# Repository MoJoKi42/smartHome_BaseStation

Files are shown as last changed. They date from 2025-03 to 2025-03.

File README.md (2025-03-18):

# smartHome_BaseStation

This Smart Home base station is built around an **ESP32** as the controller and uses an **RFM69HW** 433 MHz radio module for the wireless communication with sensors and actuators. For network communication with an MQTT server, a W5500 Ethernet PHY is used. Status information is displayed via status LEDs and an **I2C OLED display**. To improve the range of the radio system, I used an external dipol antenna. The PCB antenna works okay, but the range is not sufficient for the sensors outside my flat.

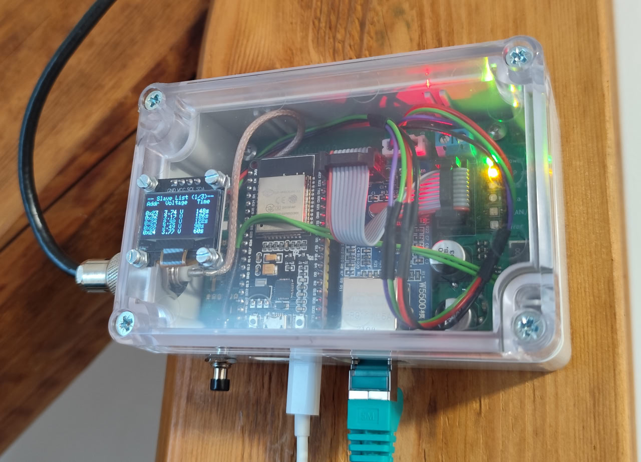
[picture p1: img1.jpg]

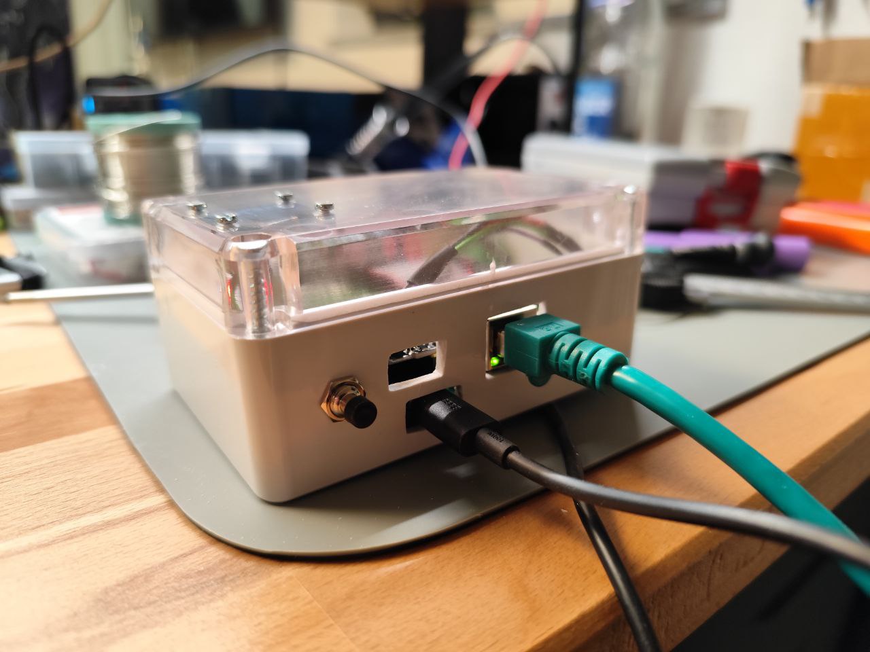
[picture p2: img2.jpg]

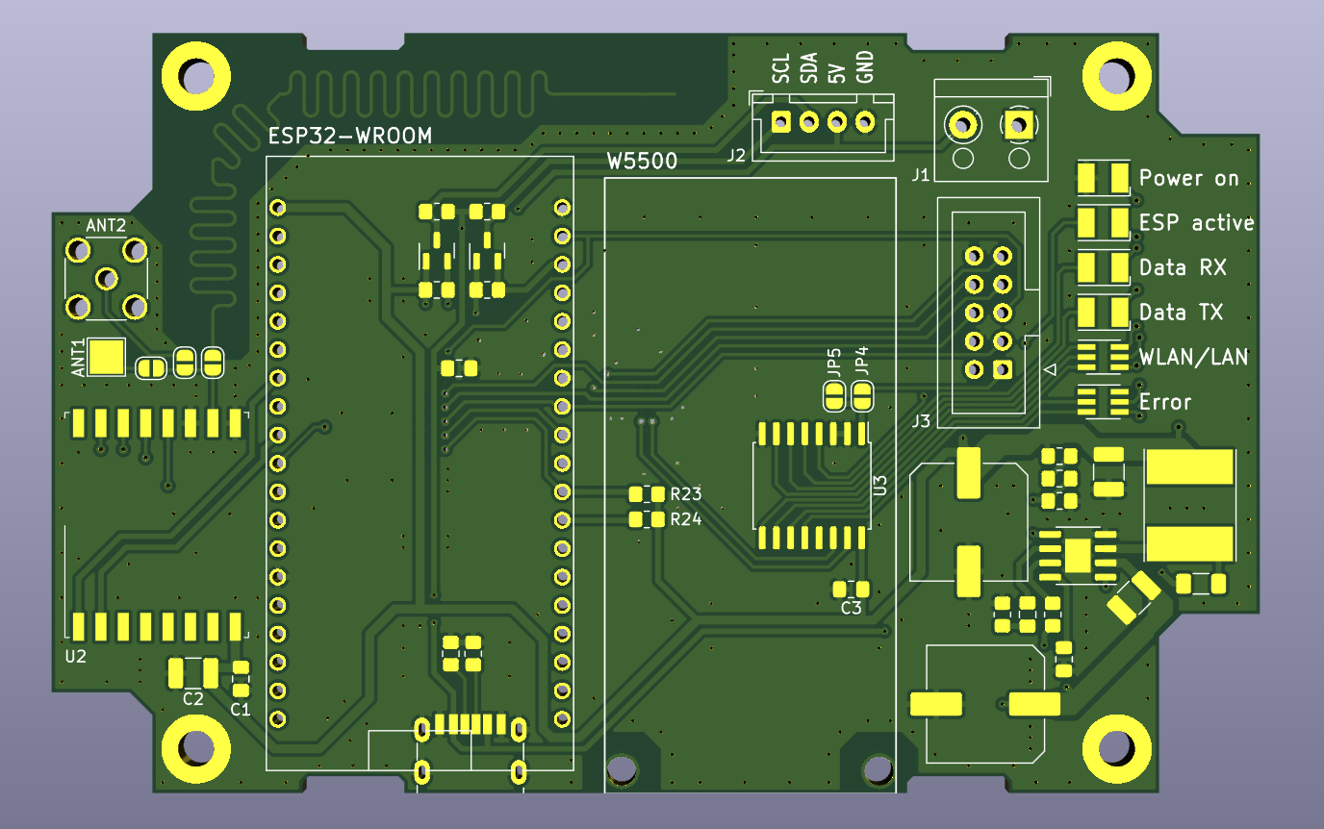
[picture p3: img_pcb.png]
img_pcb


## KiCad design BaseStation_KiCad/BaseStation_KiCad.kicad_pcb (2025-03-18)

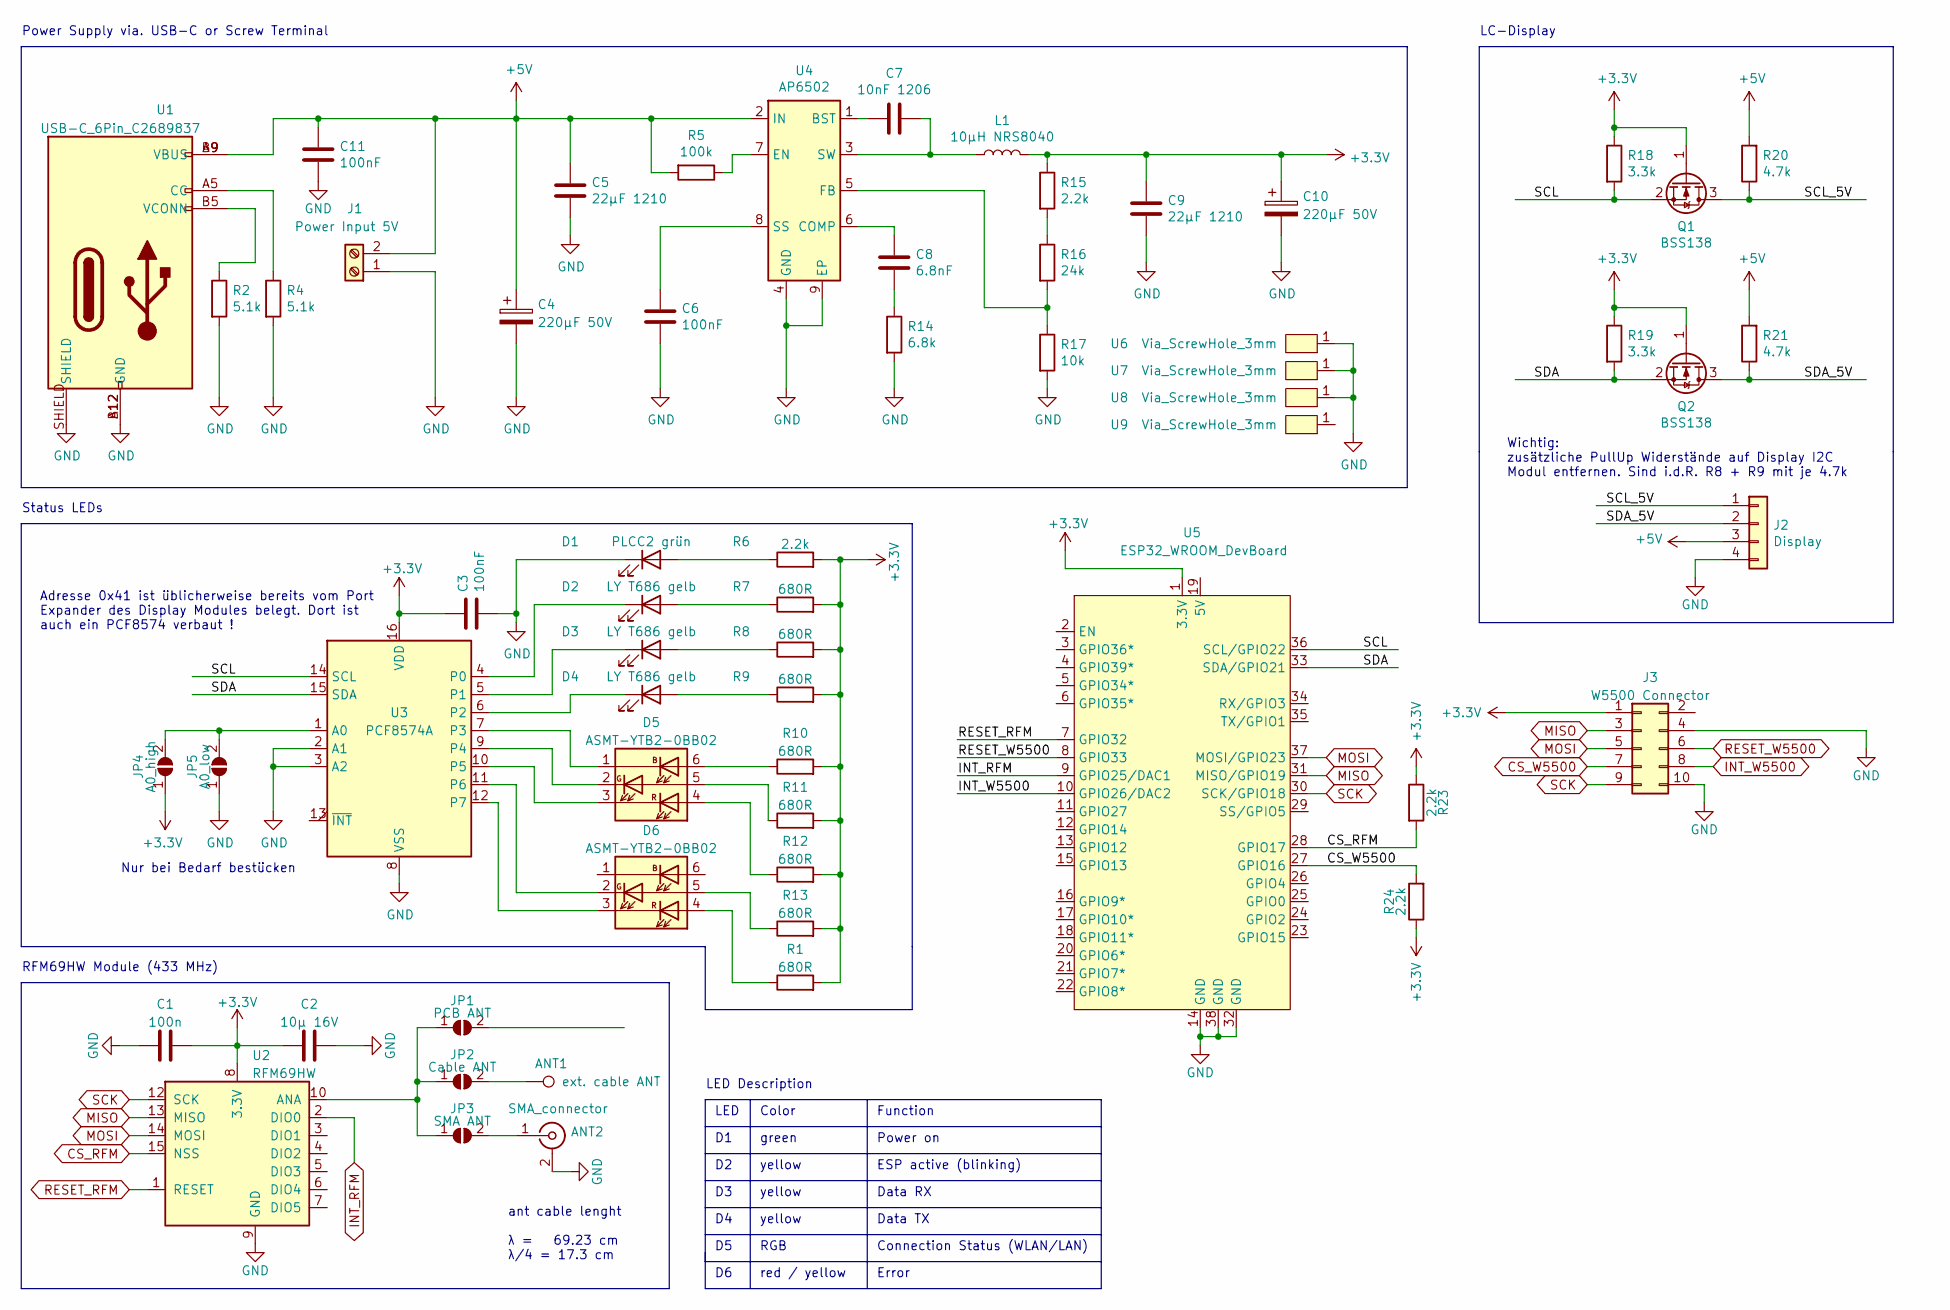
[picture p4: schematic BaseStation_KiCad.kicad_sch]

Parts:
ANT1: ext. cable ANT; TestPoint_Pad_3.0x3.0mm
ANT2: SMA_connector; SMA_Wurth_60312002114503_Vertical
C1: 100n; C_0805_2012Metric_Pad1.18x1.45mm_HandSolder
C2: 10µ 16V; C_1210_3225Metric_Pad1.33x2.70mm_HandSolder
C3, C6, C11: 100nF; C_0805_2012Metric_Pad1.18x1.45mm_HandSolder
C4, C10: 220µF 50V; C_Elec_10x10.2
C5, C9: 22µF 1210; C_1210_3225Metric_Pad1.33x2.70mm_HandSolder
C7: 10nF 1206; C_1206_3216Metric_Pad1.33x1.80mm_HandSolder
C8: 6.8nF; C_0805_2012Metric_Pad1.18x1.45mm_HandSolder
D1: PLCC2 grün; LED_PLCC-2_3.4x3.0mm_AK
D2, D3, D4: LY T686 gelb; LED_PLCC-2_3.4x3.0mm_AK
D5, D6: ASMT-YTB2-0BB02; LED_Avago_PLCC6_3x2.8mm
J1: Power Input 5V; TerminalBlock_RND_205-00001_1x02_P5.00mm_Horizontal
J2: Display; JST_XH_B4B-XH-A_1x04_P2.50mm_Vertical
J3: W5500 Connector; IDC-Header_2x05_P2.54mm_Vertical
JP1: PCB ANT; SolderJumper-2_P1.3mm_Open_RoundedPad1.0x1.5mm
JP2: Cable ANT; SolderJumper-2_P1.3mm_Open_RoundedPad1.0x1.5mm
JP3: SMA ANT; SolderJumper-2_P1.3mm_Open_RoundedPad1.0x1.5mm
JP4: A0_high; SolderJumper-2_P1.3mm_Open_RoundedPad1.0x1.5mm
JP5: A0_low; SolderJumper-2_P1.3mm_Open_RoundedPad1.0x1.5mm
L1: 10µH NRS8040; L_Taiyo-Yuden_NR-80xx_HandSoldering
Q1, Q2: BSS138; SOT-23
R1, R7, R8, R9, R10, R11, R12, R13: 680R; R_0805_2012Metric_Pad1.20x1.40mm_HandSolder
R2, R4: 5.1k; R_0805_2012Metric_Pad1.20x1.40mm_HandSolder
R5: 100k; R_0805_2012Metric_Pad1.20x1.40mm_HandSolder
R6, R15, R23, R24: 2.2k; R_0805_2012Metric_Pad1.20x1.40mm_HandSolder
R14: 6.8k; R_0805_2012Metric_Pad1.20x1.40mm_HandSolder
R16: 24k; R_0805_2012Metric_Pad1.20x1.40mm_HandSolder
R17: 10k; R_0805_2012Metric_Pad1.20x1.40mm_HandSolder
R18, R19: 3.3k; R_0805_2012Metric_Pad1.20x1.40mm_HandSolder
R20, R21: 4.7k; R_0805_2012Metric_Pad1.20x1.40mm_HandSolder
U1: USB-C_6Pin_C2689837
U2: RFM69HW; HOPERF_RFM69HW
U3: PCF8574A; SOIC-16W_7.5x10.3mm_P1.27mm
U4: AP6502; SOIC-8-1EP_3.9x4.9mm_P1.27mm_EP2.29x3mm
U5: ESP32_WROOM_DevBoard
U6, U7, U8, U9: Via_ScrewHole_3mm

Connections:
+3.3V: C1.2, C2.1, C3.1, C9.1, C10.1, J3.1, JP4.1 (A), L1.2, Q1.1 (G), Q2.1 (G), R1.2, R6.2, R7.2, R8.2, R9.2, R10.2, R11.2, R12.2, R13.2, R15.1, R18.1, R19.1, R23.1, R24.1, U2.8 (3.3V), U3.16 (VDD), U5.1 (3.3V)
+5V: C4.1, C5.1, C11.1, J1.2, J2.3, R5.2, R20.2, R21.2, U1.A9 (VBUS), U1.B9 (VBUS), U4.2 (IN)
/SCL: Q1.2 (S), R18.2, U3.14 (SCL), U5.36 (SCL/GPIO22)
/SCL_5V: J2.1, Q1.3 (D), R20.1
/SDA: Q2.2 (S), R19.2, U3.15 (SDA), U5.33 (SDA/GPIO21)
/SDA_5V: J2.2, Q2.3 (D), R21.1
CS_RFM: R23.2, U2.15 (NSS), U5.28 (GPIO17)
CS_W5500: J3.7, R24.2, U5.27 (GPIO16)
GND: ANT2.2 (Ext), C1.1, C2.2, C3.2, C4.2, C5.2, C6.2, C9.2, C10.2, C11.2, D1.1 (K), J1.1, J2.4, J3.4, J3.10, JP5.1 (A), R2.2, R4.2, R14.2, R17.2, U1.A12 (GND), U1.B12 (GND), U1.SHIELD, U2.9 (GND), U2.11 (GND), U3.2 (A1), U3.3 (A2), U3.8 (VSS), U4.4 (GND), U4.9 (EP), U5.14 (GND), U5.32 (GND), U5.38 (GND), U6.1, U7.1, U8.1
INT_RFM: U2.2 (DIO0), U5.9 (GPIO25/DAC1)
INT_W5500: J3.8, U5.10 (GPIO26/DAC2)
MISO: J3.3, U2.13 (MISO), U5.31 (MISO/GPIO19)
MOSI: J3.5, U2.14 (MOSI), U5.37 (MOSI/GPIO23)
unnamed: ANT1.1, JP2.2 (B)
unnamed: ANT2.1 (In), JP3.2 (B)
unnamed: C6.1, U4.8 (SS)
unnamed: C7.1, L1.1, U4.3 (SW)
unnamed: C7.2, U4.1 (BST)
unnamed: C8.1, U4.6 (COMP)
unnamed: C8.2, R14.1
unnamed: D1.2 (A), R6.1
unnamed: D2.1 (K), U3.4 (P0)
unnamed: D2.2 (A), R7.1
unnamed: D3.1 (K), U3.5 (P1)
unnamed: D3.2 (A), R8.1
unnamed: D4.1 (K), U3.6 (P2)
unnamed: D4.2 (A), R9.1
unnamed: D5.1 (KB), U3.7 (P3)
unnamed: D5.2 (KG), U3.9 (P4)
unnamed: D5.3 (KR), U3.10 (P5)
unnamed: D5.4 (AR), R12.1
unnamed: D5.5 (AG), R11.1
unnamed: D5.6 (AB), R10.1
unnamed: D6.2 (KG), U3.11 (P6)
unnamed: D6.3 (KR), U3.12 (P7)
unnamed: D6.4 (AR), R1.1
unnamed: D6.5 (AG), R13.1
unnamed: JP1.1 (A), JP2.1 (A), JP3.1 (A), U2.10 (ANA)
unnamed: R2.1, U1.B5 (VCONN)
unnamed: R4.1, U1.A5 (CC)
unnamed: R5.1, U4.7 (EN)
unnamed: R15.2, R16.1
unnamed: R16.2, R17.1, U4.5 (FB)
unnamed: JP4.2 (B), JP5.2 (B), U3.1 (A0)
RESET_RFM: U2.1 (RESET), U5.7 (GPIO32)
RESET_W5500: J3.6, U5.8 (GPIO33)
SCK: J3.9, U2.12 (SCK), U5.30 (SCK/GPIO18)

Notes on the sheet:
RFM69HW Module (433 MHz)
Connection Status (WLAN/LAN)
Wichtig: zusätzliche PullUp Widerstände auf Display I2C Modul entfernen. Sind i.d.R. R8 + R9 mit je 4.7k
Function
LED
ESP active (blinking)
RGB
LC-Display
green
ant cable lenght λ = 69.23 cm λ/4 = 17.3 cm
Power Supply via. USB-C or Screw Terminal
yellow
LED Description
Data RX
red / yellow
Error
Adresse 0x41 ist üblicherweise bereits vom Port Expander des Display Modules belegt. Dort ist auch ein PCF8574 verbaut !
Status LEDs
Color
Nur bei Bedarf bestücken
Data TX
Power on

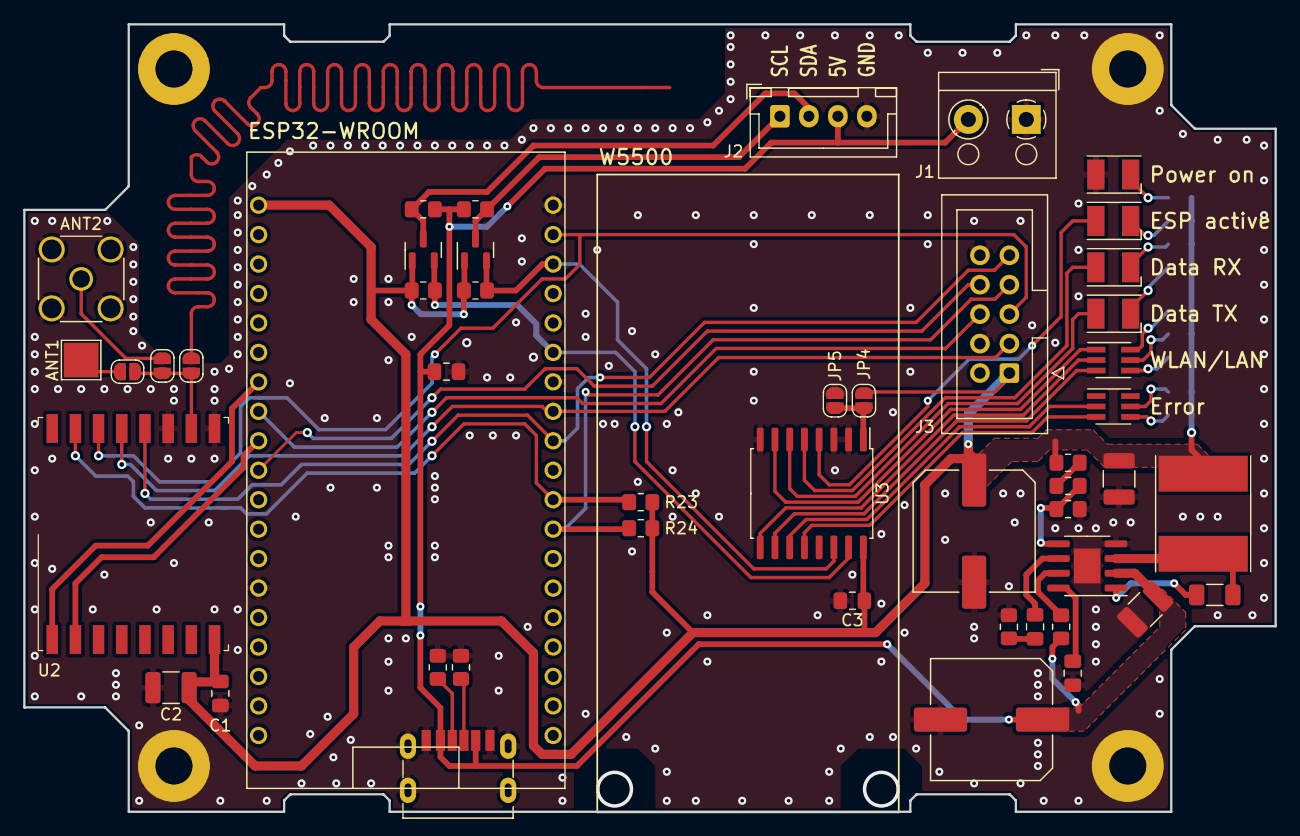
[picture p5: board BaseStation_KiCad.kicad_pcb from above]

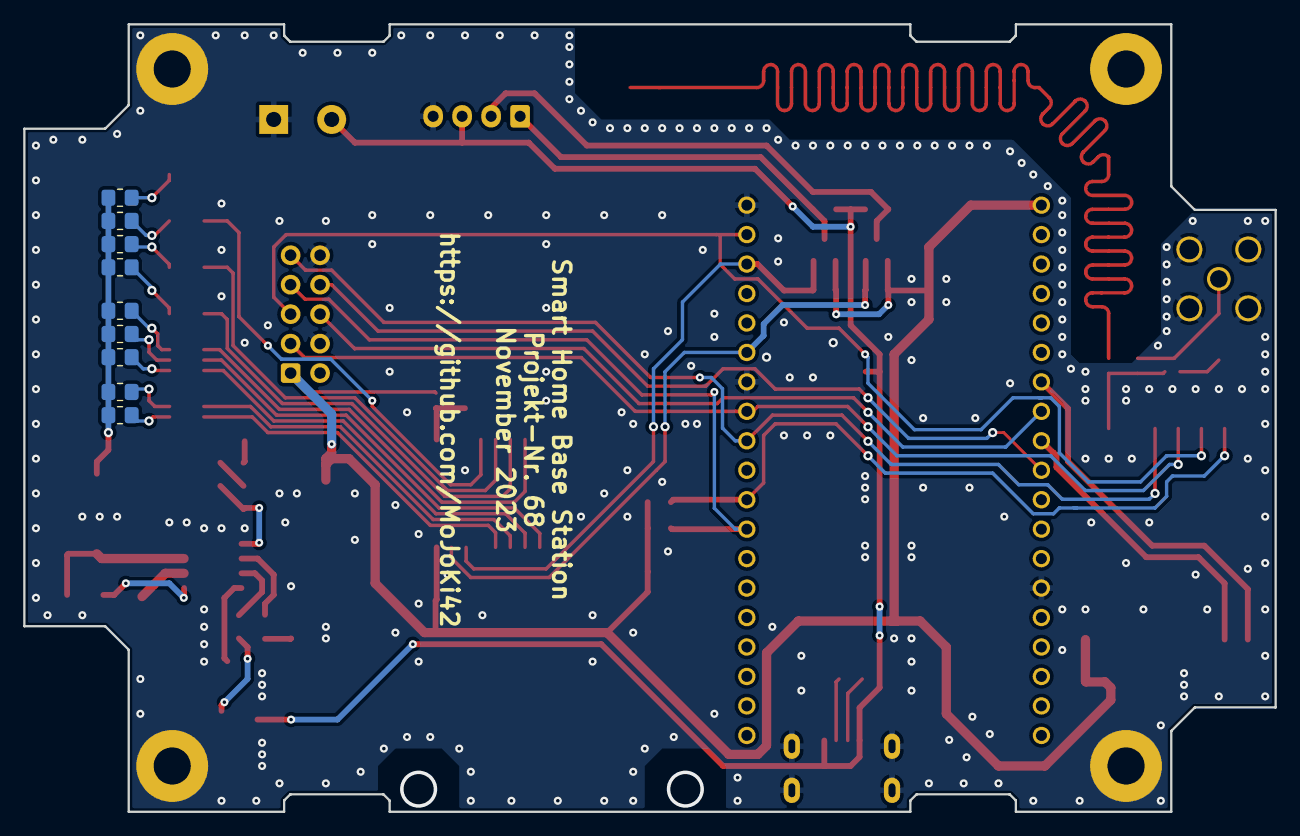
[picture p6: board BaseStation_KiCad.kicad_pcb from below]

Board: 2 copper layers, 107.9 x 67.9 mm, 61 parts (9 on the bottom side), 47 nets.

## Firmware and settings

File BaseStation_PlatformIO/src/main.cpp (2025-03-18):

#include <Arduino.h>
#include <PCF8574.h>
#include <Ethernet.h>
#include <Wire.h>
#include <SPI.h>
#include <RFM69.h>
#include <Adafruit_GFX.h>
#include <Adafruit_SSD1306.h>
#include <PubSubClient.h>
#include "disp.h"
#include "main.h"
#include "radio.h"

// Debug Konsole:
// sudo minicom -D /dev/ttyUSB0 -b 115200
// (to exit: Strg+A -> Q -> Enter)


radio_t radio_drv;
IPAddress ipAddress;
PubSubClient mqttClient;
EthernetClient ethClient;
uint32_t lastMqttPublishTime = 0;


// PCF8574 (for LEDs)
PCF8574 LEDs_PCF8574(0x39);

// OLED
#define OLED_WIDTH  128
#define OLED_HEIGHT 64
Adafruit_SSD1306 display(OLED_WIDTH, OLED_HEIGHT);
disp_t disp;

// RFM69
SPIClass * vspi = NULL;
RFM69 radio(PIN_CS_RFM, PIN_INT_RFM, true, vspi);

// prototypes
void macCharArrayToBytes(const char* str, byte* bytes);
void ethernetWizReset(const uint8_t resetPin);
void connectEthernet();
void mqttCallback(char* topic, byte* payload, unsigned int length);
void mqttReconnect();
void publish_mqtt(uint8_t nodeID, char* payload, uint8_t payload_lenght);
uint32_t time_func(uint32_t time_diff);

// prototypes rfm + receive function
uint8_t rfm_transmit(uint8_t dest, uint8_t* data, uint8_t len);
uint8_t rfm_receive(uint8_t* src, uint8_t* data, uint8_t* len);
uint8_t rfm_sendACK(uint8_t dest);
uint8_t rfm_ACKReceived(uint8_t dest);
uint8_t rfm_ACKRequested(uint8_t src);
uint8_t rfm_receiveDone(void);
void receive(uint8_t source, uint8_t* data, uint16_t len);

// variables
static uint32_t time_rxLED = time_func(0);

void setup() {
  Serial.begin(115200);   // init UART
  LEDs_PCF8574.begin();   // init PCF8574
  LEDs_PCF8574.write(LED_status_LAN_red,   0);
  LEDs_PCF8574.write(LED_status_error_red, 0);

  // Outputs
  pinMode(PIN_BUTTON, INPUT_PULLUP);

  // OLED
  display.begin(SSD1306_SWITCHCAPVCC, 0x3C);
  display.clearDisplay();
  display.display();
  display.setTextSize(1);
  display.setTextColor(SSD1306_WHITE);

  // Display Lib init
  disp_init(&disp, &display, ETHERNET_IP, MQTT_HOSTNAME);

  // MQTT / Ethernet
  connectEthernet();
  ethClient.setConnectionTimeout(1000);
  mqttClient.setClient(ethClient);
  mqttClient.setServer(MQTT_HOSTNAME, MQTT_PORT);
  mqttReconnect();

  // RFM69 init
  vspi = new SPIClass(VSPI);
  radio.initialize(FREQUENCY,NODEID,NETWORKID);
  radio.setHighPower();
  radio.encrypt(ENCRYPTKEY);

  // radio lib init
  radio_init(&radio_drv, NODEID);
  radio_set_cb_rfm (&radio_drv, (void*)rfm_transmit, (void*)rfm_receive, (void*)rfm_sendACK, (void*)rfm_ACKReceived, (void*)rfm_ACKRequested, (void*)rfm_receiveDone);
  radio_set_cb_func(&radio_drv, (void*)receive, (void*)delay, (void*)NULL);
}

void loop() {

  // MQTT / Ethernet connecting functions
  if (!ethClient.connected()) {
    LEDs_PCF8574.write(LED_status_LAN_red, 0);
  } else {
    LEDs_PCF8574.write(LED_status_LAN_red, 1);
  }
  if (!mqttClient.connected()) {
    LEDs_PCF8574.write(LED_status_error_red, 0);
    mqttReconnect();
  } else {
    LEDs_PCF8574.write(LED_status_error_red, 1);
  }
  mqttClient.loop();

  // LED status
  static uint32_t time_StatusLED = time_func(0);
  if (time_func(time_StatusLED) > 800) {
    LEDs_PCF8574.toggle(LED_status_ESP_active);
    time_StatusLED = time_func(0);
  }

  // LEDs tx + rx
  static uint32_t time_txLED = time_func(0);
  if (!radio_buffer_empty_tx(&radio_drv)) {
    LEDs_PCF8574.write(LED_status_data_TX, 0);
    time_txLED = time_func(0);
  }
  if (time_func(time_rxLED) > 200) {
    LEDs_PCF8574.write(LED_status_data_RX, 1);
  }
  if (time_func(time_txLED) > 200) {
    LEDs_PCF8574.write(LED_status_data_TX, 1);
  }

  // radio
  radio_loop(&radio_drv);

  // button
  static uint32_t time_Button01 = time_func(0);
  if (!digitalRead(PIN_BUTTON) && time_func(time_Button01) > 200) {
    disp_set_next_page(&disp);
    time_Button01 = time_func(0);
  }

  // display refresh
  static uint32_t time_DisplayRefresh = time_func(0);
  if (time_func(time_DisplayRefresh) > 100) {
    disp_refresh_display(&disp);
    time_DisplayRefresh = time_func(0);
  }
}

void publish_mqtt(uint8_t nodeID, char* payload, uint8_t payload_lenght) {

  // generate address strings
  char node_id[3];
  char type_id[3];
  char base_id[3];
  uint8_t base_id_int = NODEID;
  sprintf(node_id, "%02x", nodeID);
  sprintf(type_id, "%02x", nodeID & 0xF0);
  sprintf(base_id, "%02x", base_id_int);
    
  // generate topic string
  char topic[50];
  strcpy(topic, "base_0x");
  strcat(topic, base_id);
  strcat(topic, "_rx/nodes_0x");
  strcat(topic, type_id);
  strcat(topic, "/node_0x");
  strcat(topic, node_id);

  // publish + workaround to avoid additional invalid characters
  // looks like something in the mqtt lib is ignoring the lenght and just looking for a \0 in the string
  uint8_t* pnt = (uint8_t*)malloc(payload_lenght + 1);
  memcpy(pnt, payload, payload_lenght);
  pnt[payload_lenght] = '\0';
  mqttClient.publish(topic, pnt, payload_lenght);
  free(pnt);

  // Debug Output
  Serial.print("<- ");
  Serial.print(topic);
  Serial.print(" = ");
  for (byte i = 0; i < payload_lenght; i++) {
      if (payload[i] >= 32 && payload[i] <= 126) {
        Serial.print(payload[i]);
      } else {
        Serial.print(".");
      }
  }
  Serial.print("\n\r");
}


/////////////////////////////////////////////////////////////////////////////
// W5500 & MQTT functions
// Source: https://github.com/jozala/ESP32_W5500_MQTT
/////////////////////////////////////////////////////////////////////////////

void macCharArrayToBytes(const char* str, byte* bytes) {
    for (int i = 0; i < 6; i++) {
        bytes[i] = strtoul(str, NULL, 16);
        str = strchr(str, ':');
        if (str == NULL || *str == '\0') {
            break;
        }
        str++;
    }
}

void ethernetWizReset(const uint8_t resetPin) {
    pinMode(resetPin, OUTPUT);
    digitalWrite(resetPin, HIGH);
    delay(250);
    digitalWrite(resetPin, LOW);
    delay(50);
    digitalWrite(resetPin, HIGH);
    delay(350);
}

void connectEthernet() {
    delay(500);
    byte* mac = new byte[6];
    macCharArrayToBytes(ETHERNET_MAC, mac);
    ipAddress.fromString(ETHERNET_IP);

    Ethernet.init(ETHERNET_CS_PIN);
    ethernetWizReset(ETHERNET_RESET_PIN);

    Serial.println("Starting ETHERNET connection...");
    Ethernet.begin(mac, ipAddress);
    delay(200);

    Serial.print("Ethernet IP is: ");
    Serial.println(Ethernet.localIP());
}

void mqttCallback(char* topic, byte* payload, unsigned int length) {

  // get destination & len
  uint8_t topic_len = strlen(topic);
  uint8_t destination = 0x00;
  if (topic_len == 22) {
    destination = (uint8_t)strtol((topic + 18), NULL, 0);
  }
  if (destination == 0x00) {
    LEDs_PCF8574.write(LED_status_data_TX, 1);
    return;
  }

  // transmit
  radio_transmit(&radio_drv, destination, (uint8_t*)payload, length);
  
  // store msg to display lib
  disp_add_tx(&disp, destination, (char*)payload, length);
}

void mqttReconnect() {
  Serial.print("Connecting to MQTT broker ");
  Serial.println(MQTT_HOSTNAME);

  char deviceName[20];
  char base_id[3];
  uint8_t base_id_int = NODEID;
  sprintf(base_id, "%02x", base_id_int);
  strcpy(deviceName, "base_0x");
  strcat(deviceName, base_id);
  while(!mqttClient.connect(deviceName)) {
    Serial.print("Connecting to MQTT as ");
    Serial.println(deviceName);
    delay(1000);
  }
  Serial.print("Connected to MQTT as ");
  Serial.print(deviceName);
  Serial.print(" (");
  Serial.print(Ethernet.localIP());
  Serial.println(")");

  // subscribe "base_0x01_tx"
  strcat(deviceName, "_tx/+");
  mqttClient.setCallback(mqttCallback);
  mqttClient.subscribe(deviceName);
  Serial.print("Subscribed topic \"");
  Serial.print(deviceName);
  Serial.println("\"");
}


/////////////////////////////////////////////////////////////////////////////
// RFM + radio lib functions
/////////////////////////////////////////////////////////////////////////////

uint8_t rfm_transmit(uint8_t dest, uint8_t* data, uint8_t len) {
  radio.send(dest, data, len, true);
  return 0;
}

uint8_t rfm_receive(uint8_t* src, uint8_t* data, uint8_t* len) {
  *len = radio.DATALEN;
  *src = radio.SENDERID;
  for (int i=0; i<*len && i<RF69_MAX_DATA_LEN; i++) {
    data[i] = radio.DATA[i];
  }
  return 0;
}

uint8_t rfm_sendACK(uint8_t dest) {
  radio.sendACK();
  return 0;
}

uint8_t rfm_ACKReceived(uint8_t dest) {
  return radio.ACKReceived(dest);
}

uint8_t rfm_ACKRequested(uint8_t src) {
  return radio.ACKRequested();
}

uint8_t rfm_receiveDone(void) {
  return radio.receiveDone();
}

void receive(uint8_t source, uint8_t* data, uint16_t len) {

  // publish to MQTT
  publish_mqtt(source, (char*)data, len);

  // store msg to display lib
  disp_add_rx(&disp, source, (char*)data, len);

  // RX LED
  LEDs_PCF8574.write(LED_status_data_RX, 0);
  time_rxLED = time_func(0);
}


/////////////////////////////////////////////////////////////////////////////
// various functions
/////////////////////////////////////////////////////////////////////////////

uint32_t time_func(uint32_t time_diff) {
	uint32_t time = millis();
	time = (0x7FFFFFFF & time) - (0x7FFFFFFF & time_diff);
	if (time & 0x80000000) {
		time = time + 0x80000000;
	}
	return time;
}

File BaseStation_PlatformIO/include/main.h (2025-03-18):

#define LED_status_ESP_active   0
#define LED_status_data_RX      1
#define LED_status_data_TX      2
#define LED_status_LAN_blue     3
#define LED_status_LAN_green    4
#define LED_status_LAN_red      5
#define LED_status_error_green  6
#define LED_status_error_red    7

#define PIN_CS_RFM      17
#define PIN_INT_RFM     25
#define PIN_CS_W5500    16
#define PIN_BUTTON      4


#define NODEID          0x01    // keep UNIQUE for each node on same network
#define NETWORKID       33      // keep IDENTICAL on all nodes that talk to each other
#define FREQUENCY       RF69_433MHZ
#define ENCRYPTKEY      "1234567812345678"


// MQTT / Ethernet
// Source: https://github.com/jozala/ESP32_W5500_MQTT
#define ETHERNET_MAC            "FF:FF:FF:FF:FF:FF" // Ethernet MAC address
#define ETHERNET_IP             "192.168.150.100"   // IP address of Ethernet connection
#define ETHERNET_RESET_PIN      33                  // ESP32 pin where reset pin from W5500 is connected
#define ETHERNET_CS_PIN         16                  // ESP32 pin where CS pin from W5500 is connected
#define MQTT_HOSTNAME           "192.168.150.101"
#define MQTT_PORT                   1883
#define MQTT_PUBLISH_INTERVAL_MS    250


// MQTT tree example
/*
base_0x01_rx
           ├── nodes_0x10
           │            ├── node_0x11 = {...}
           │            └── node_0x12 = {...}
           └── nodes_0x20
                        ├── node_0x21 = {...}
                        └── node_0x22 = {...}
base_0x01_tx
           ├── node_0x11 = {...}
           └── node_0x32 = {...}

base_0x01_stats
              ├── uptime = 
              ├── packets_rx = 
              └── packets_tx =
*/
